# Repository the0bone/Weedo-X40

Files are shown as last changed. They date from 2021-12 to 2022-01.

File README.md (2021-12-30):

# Weedo-X40
My work for the Weedo X40 IDEX 3D printer

## Youtube Review (german)
Watch and Like my Video on YouTube. Even if you don't understand German, YouTube will give me some Cents for your click.
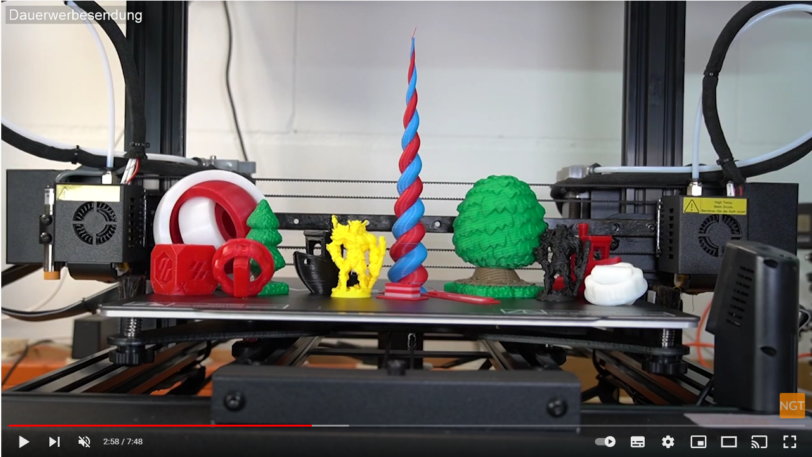
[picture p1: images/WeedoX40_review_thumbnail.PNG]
German Weedo X40(v2) 3D Drucker Review (https://www.youtube.com/watch?v=y7d468NICiw "German Weedo X40(v2) 3D Drucker Review")


# PrusaSlicer Profile
While PrusaSlicer 2.4 includes PaintOn MultiMaterial, it is the optimal Slicer for the Weedo X40.
Therefor I tried to create Profiles that will run with the default firmware.
The released profiles are for:

- Single Nozzle Print  
Use the left Extruder to make a single print. The options to select Mirror or Duplication via the screen on the printer are not available.

- Dual Nozzle Print  
Use both  Extruder to make a single print. Use a wipe tower to prime each nozzle before it will print.
Use Purging Volumes on the right and set it to 30mm² in the advanced section, if that is not included in the profile.

- Double Nozzle Print  
Because the selection is not available from the print screen, you can directly slice the object for that mode. You can also only see half of the print bed.

# RepRap conversion
Follow me along how I turned the X40 into a Printer using RepRap Firmware. [--> Go to RRF](RRF/)

# Donations
If you like, you can let Amazon pay some donations to me by using this affiliate link for your next pruchases on Amazon Germany: https://amzn.to/3cwmAMx

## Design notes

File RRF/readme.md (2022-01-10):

# Weedo X40 transition into RepRap Firmware printer

You need:
* Weedo X40(v2)
* Fysetc Big Dipper
* (alternative: Duet 3 Mini 5+ & Duet 3 Expansion for at least 2 additional drivers=
* Wires
* [JST SM](https://amzn.to/3GhMfW4) & [JST XH](https://amzn.to/3omI1pY)
* Good Crimping Tool [ENGINEER PA-09](https://amzn.to/3os2x8O)
* Printed Holder (best in ABS (plus) and 5 outer perimeters)

## Wire Diagram
This is how I wired the IDEX printer with his two extruders, dual axis and all endstops.
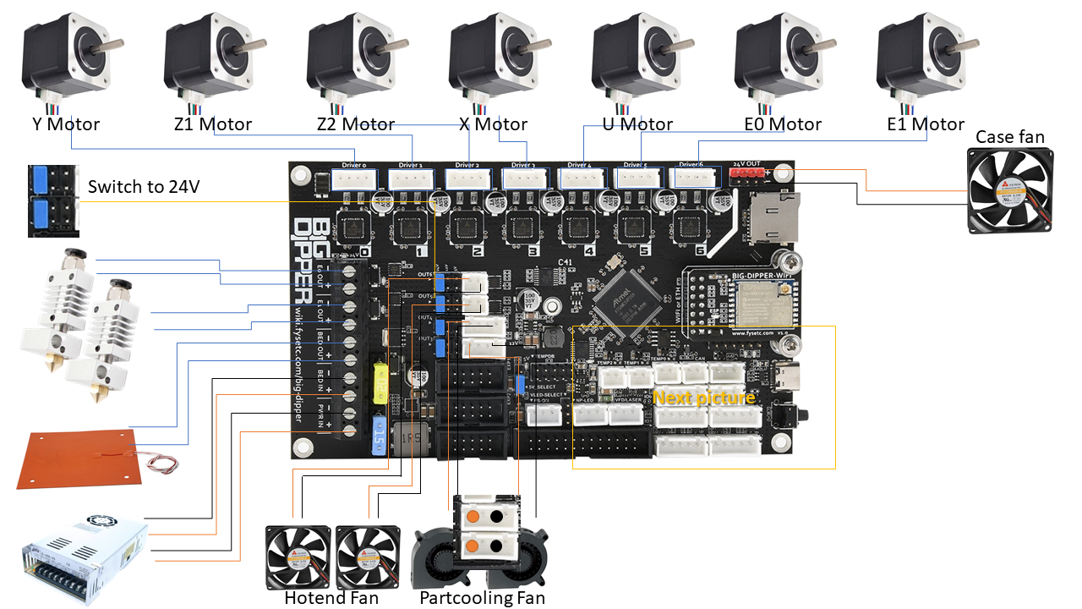
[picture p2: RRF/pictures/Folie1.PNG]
Pinning 1

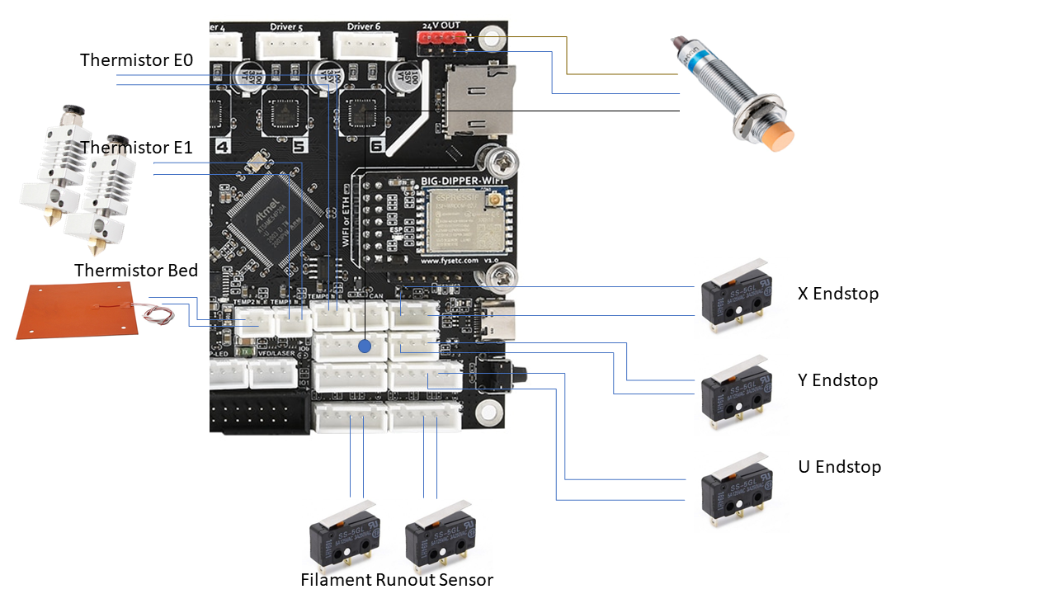
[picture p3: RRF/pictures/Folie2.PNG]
Pinning 2


If it is not clear to see, I also did some pictures.
For the Y and both Z Motors, I used the exising cables. For both E and X I bought new cables with 1m length.

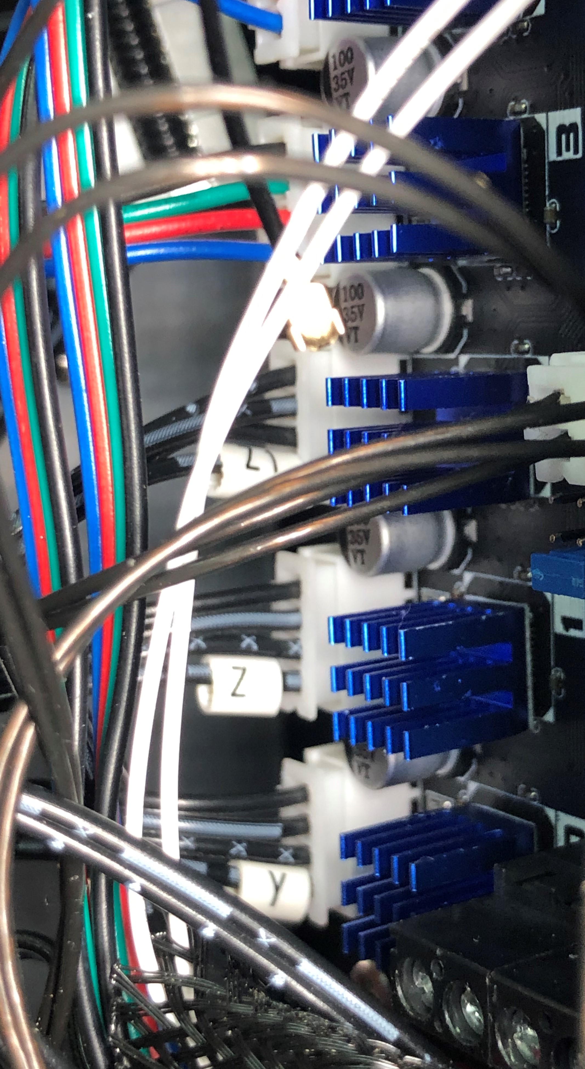
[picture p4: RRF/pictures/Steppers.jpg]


For the Fans on the Hotend you need to set the Jumpers to 24V. See the pinning on the picture.

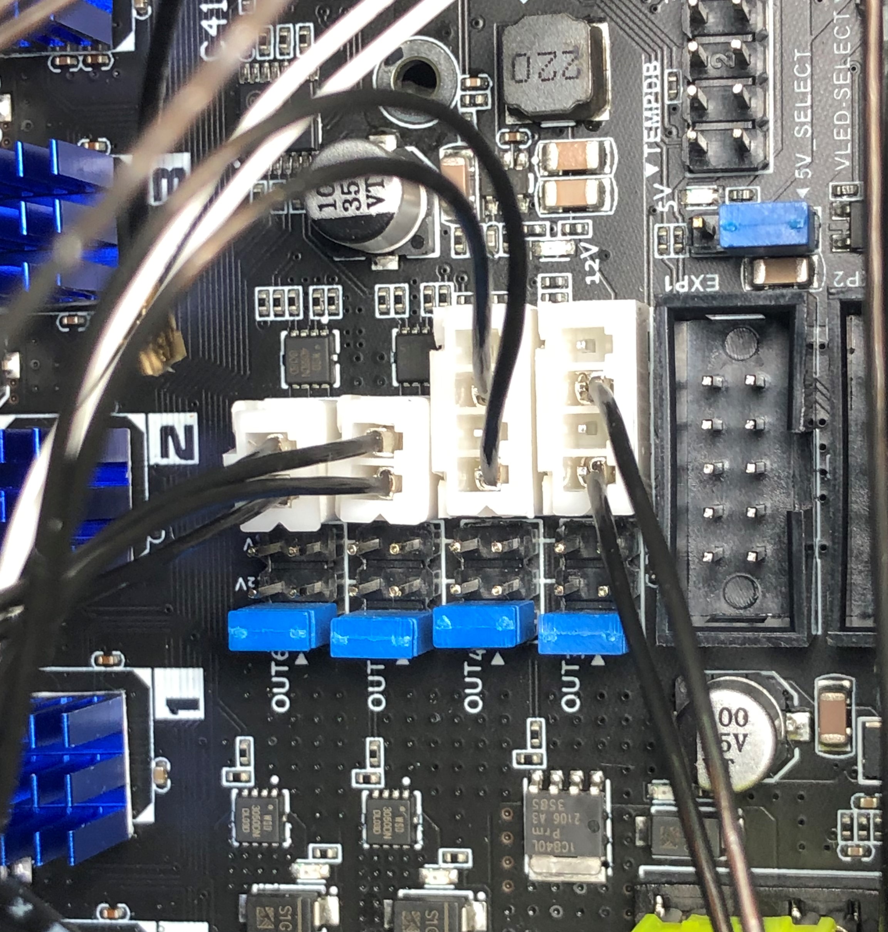
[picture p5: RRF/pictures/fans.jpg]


Also for the Endstops and the proximity sensor the Pinning is very impotant. There is no polarity but you have to take the right PINs in the JST-XH connectors.

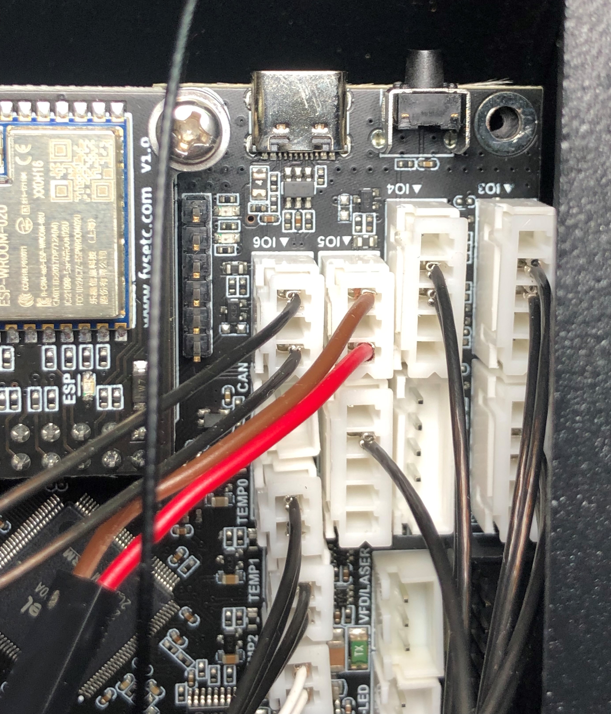
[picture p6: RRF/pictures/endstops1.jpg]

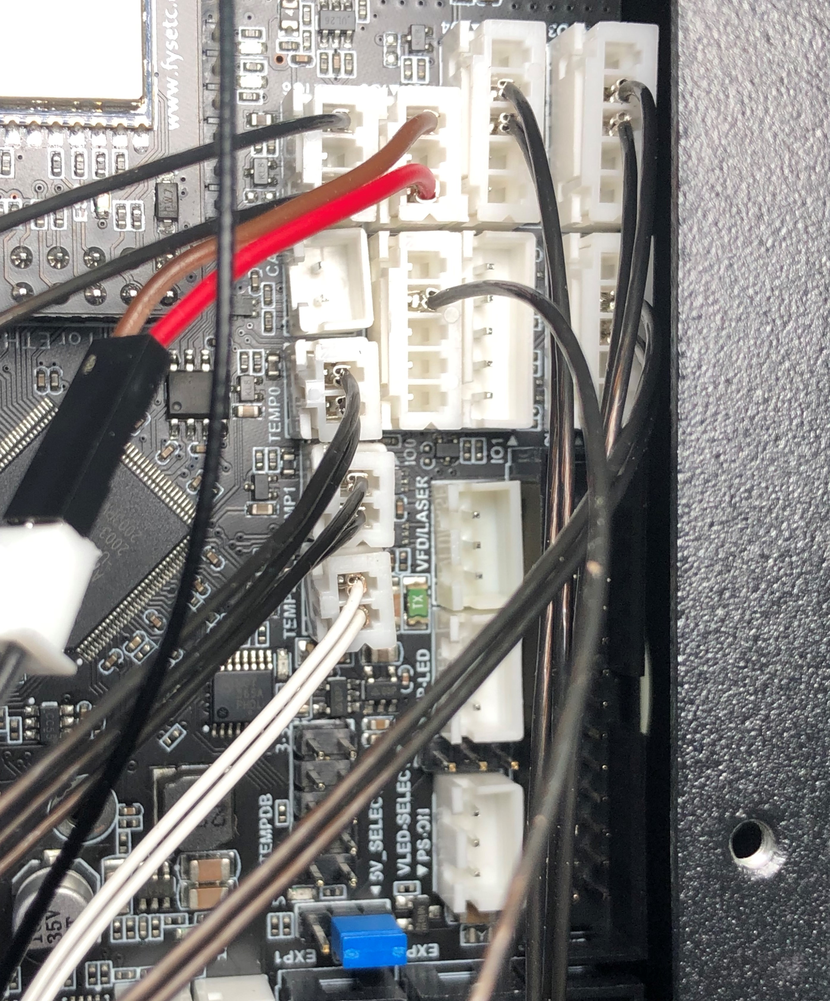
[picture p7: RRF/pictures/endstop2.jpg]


## PINout
| Function | PIN | comment |
| --- | --- | --- |
| Y Axis Motor | Driver 0 | |
| Z1 Axis Motor | Driver 1 | |
| Z2 Axis Motor | Driver 2 | |
| X Axis Motor | Driver 3 | left Printhead |
| U Axis Motor | Driver 4 | right Printhead |
| E0 Axis Motor | Driver 5 | left Extruder |
| E1 Axis Motor | Driver 6 | right Extruder |
| PSU 24V | Pwr in | |
| PSU 24V | Bed in | |
| Heated Bed | Bed out | |
| Hotend E0 | E0 out | left Printhead |
| Hotend E1 | E1 Out | right  Printhead |
| X-Endstop | io6.in | see pic for PIN |
| U-Endstop | io4.in | see pic for PIN |
| Y-Endstop | io5.in | see pic for PIN |
| Z-Probe | io0.in | only for Signal, see pic for PIN |
| Bed Thermistor | out0 |  |
| E0  Thermistor | out1 |  |
| E1  Thermistor | out2 |  |
| Case fan | 24V out |  |
| Z-Probe | 24V out |  |

## Results
Even if I'm still have the way down, the results are similar from quality but printed way faster with 80mm/sec that are also reached with the current settings.

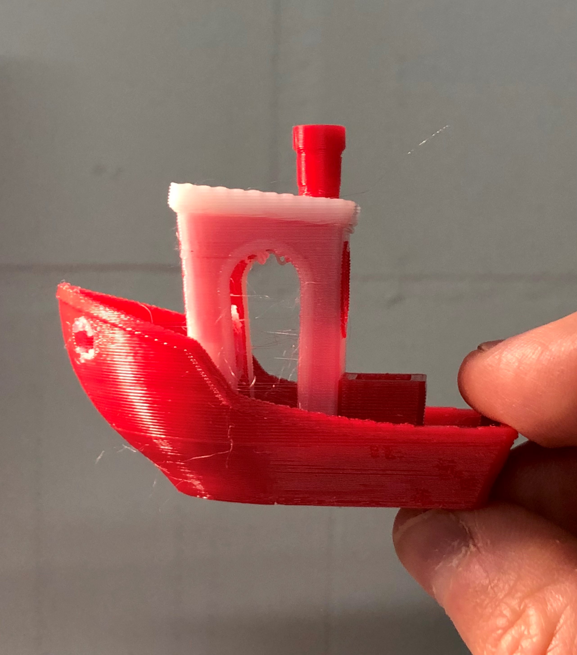
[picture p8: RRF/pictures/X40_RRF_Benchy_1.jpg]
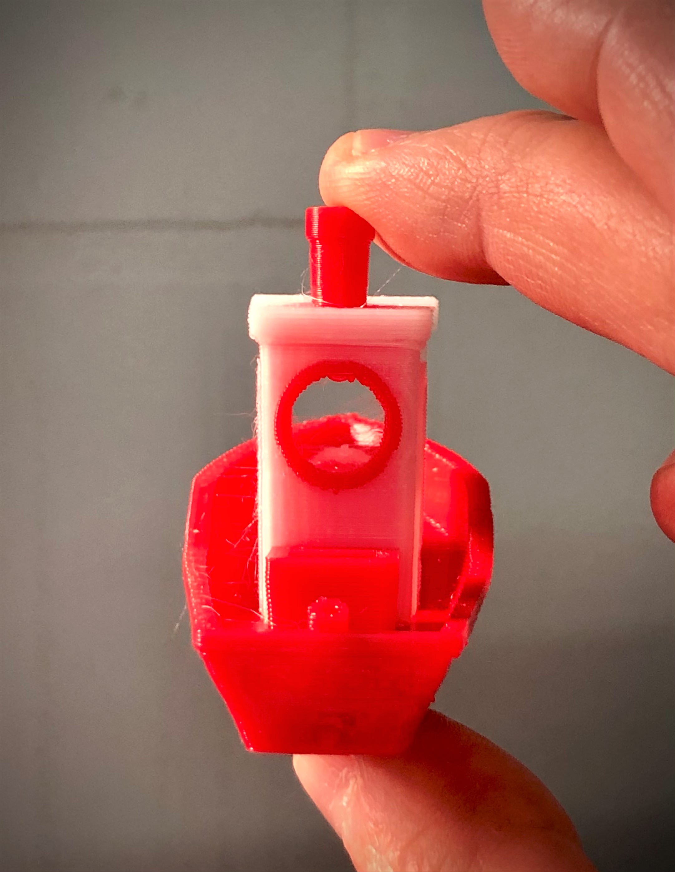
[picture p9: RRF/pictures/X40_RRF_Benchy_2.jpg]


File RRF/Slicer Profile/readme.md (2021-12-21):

Slicer Profiles for Prusa Slicer 2.4 that work together with the RRF on the Board.

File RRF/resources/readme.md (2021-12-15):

Each printer is a little different. You can carry over most of the setting. But some you need to tune for your printer.
Here is a link list of resources that you should visit to avoid the printer crashing into the bed for example.

First you need to tell the board about your WiFi.
I did that with Pronterface and this steps: https://duet3d.dozuki.com/Guide/1.)+Getting+Connected+to+your+Duet/7

Tipp: If you add ' before a letter, also Pronterface allowes small Letters. P'A'S'S'W'O'R'D = Password

Test and calibrate a Z probe https://duet3d.dozuki.com/Wiki/Test_and_calibrate_the_Z_probe#Section_Calibrate_the_Z_probe_trigger_height
Calibrate IDEX https://duet3d.dozuki.com/Wiki/ConfiguringMultipleIndependentXcarriagesCartesian#Section_Calibration

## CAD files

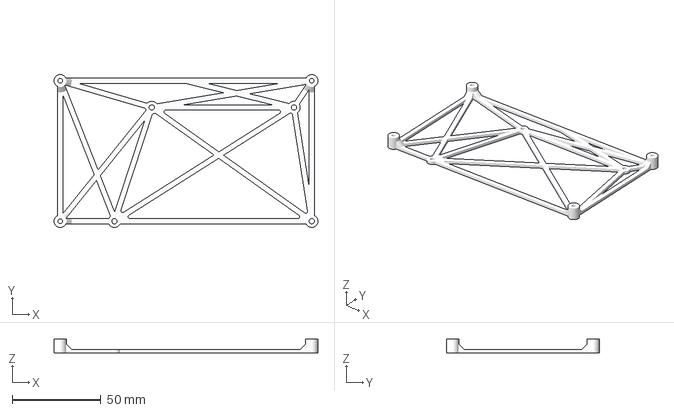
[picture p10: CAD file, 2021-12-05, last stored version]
Big Dipper/WeedoX40_FysetcBigDipper_Holder.3mf
148.5 x 86.0 x 8.00 mm

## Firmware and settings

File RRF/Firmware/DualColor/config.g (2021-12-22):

; Configuration file for Duet 3 Mini 5+ (firmware version 3.3)
; executed by the firmware on start-up
;
; generated by RepRapFirmware Configuration Tool v3.3.10 on Fri Dec 10 2021 21:27:52 GMT+0100 (Mitteleuropäische Normalzeit)

; General preferences
G90                                             ; send absolute coordinates...
M83                                             ; ...but relative extruder moves
M550 P"Weedo X40v2"                             ; set printer name

; Wait a moment for the CAN expansion boards to start
G4 S2

; Network
M551 P"reprap"                                  ; set password
M552 S1                                         ; enable network
M586 P0 S1                                      ; enable HTTP
M586 P1 S0                                      ; disable FTP
M586 P2 S0                                      ; disable Telnet

; Drives
M569 P0.0 S0 V50                                    ; Y Axis physical drive 0.0 goes backwards V50 to leave spreadCycle Mode
M569 P0.1 S0 V50                                    ; Z left Axis physical drive 0.1 goes backwards 
M569 P0.2 S0 V50                                    ; Z right Axis physical drive 0.2 goes backwards 
M569 P0.3 S1 V50                                    ; X left Axis physical drive 0.3 goes forwards 
M569 P0.4 S0 V50                                    ; X right Axis physical drive 0.4 goes backwards 
M569 P0.5 S1 V50                                    ; E left Axis physical drive 0.5 goes forwards 
M569 P0.6 S1 V50                                    ; E right Axis physical drive 0.6 goes forwards 
M584 X0.3 Y0.0 Z0.1:0.2 U0.4 E0.5:0.6               ; set drive mapping, Driver number for additional axes U for second X
M350 X16 Y16 Z16:16 U16 E16:16 I1                   ; configure microstepping with interpolation
M92 X94.14 Y94.14 Z400.00:400.00 U94.14 E94.90:94.90 ; set steps per mm
M566 X660.00 Y660.00 Z600.00:600.00 U660.00 E300.00:300.00   ; set maximum instantaneous speed changes (mm/min) (jerk) !!! mm/min = 60 x mm/sec
M203 X12000.00 Y7800.00 Z300.00:300.00 U12000.00 E1500.00:1500.00  ; set maximum speeds (mm/min) !!! mm/min = 60 x mm/sec
M201 X3000.00 Y3000.00 Z3000.00:3000.00 U3000.00 E3000.00:3000.00      ; set accelerations (mm/s^2)   (old 1000 and 20 for Z)
M906 X700 Y700 Z700:700 U700 E500:500 I30           ; set motor currents (mA) and motor idle factor in per cent
M84 S30                                             ; Set idle timeout

; Axis Limits
M208 X-51.80 U0 Y-11 Z0:0 S1                        ; set axis minima, X-51.8 for the Extruder to go negative into park position, S1 = set axis minimum
M208 X300.00 U351.80 Y305 Z400:400 S0               ; set axis maxima, U351.8 for the Extruder to go out of bed into park position, S0 = set axis maximum

; Endstops
M574 X1 S1 P"!io6.in"                            ; configure switch-type (e.g. microswitch) endstop for low end on X via pin io6.in
M574 U2 S1 P"!io4.in"                            ; configure switch-type (e.g. microswitch) endstop for high end on U via pin io4.in
M574 Y1 S1 P"!io5.in"                            ; configure switch-type (e.g. microswitch) endstop for low end on Y via pin io5.in
M574 Z1 S2                                      ; configure Z-probe endstop for low end on Z

; Z-Probe
M558 P5 C"!io0.in" H5 F240 T10000               ; set Z probe type to unmodulated and the dive height + speeds for Probing and Travel
G31 P500 X-35 Y0 Z1.030                           ; set Z probe trigger value, offset and trigger height
M557 X10:290 Y10:290 S50                        ; set Mesh bed size

; Heaters
M308 S0 P"temp2" Y"thermistor" T100000 B4092    ; configure sensor 0 as thermistor on pin temp2
M950 H0 C"out0" T0                              ; create bed heater output on out0 and map it to sensor 0
M307 H0 B0 R0.317 C372.9 D3.16 S1.00 V24.1      ; disable bang-bang mode for the bed heater and set PWM limit with PID tune
M140 H0                                         ; map heated bed to heater 0
M143 H0 S100                                    ; set temperature limit for heater 0 to 100C
M308 S1 P"temp0" Y"thermistor" T100000 B4092    ; configure sensor 1 as thermistor on pin temp0
M950 H1 C"out1" T1                              ; create nozzle heater output on out1 and map it to sensor 1
M307 H1 B0 R3.302 C205.8 D7.27 S1.00 V24.1      ; disable bang-bang mode for the bed heater and set PWM limit with PID tune
M143 H1 S260                                    ; set temperature limit for heater 1 to 260C
M308 S2 P"temp1" Y"thermistor" T100000 B4092    ; configure sensor 2 as thermistor on pin temp1
M950 H2 C"out2" T2                              ; create nozzle heater output on out2 and map it to sensor 2
M307 H2 B0 R3.528 C210.1 D7.19 S1.00 V24.1      ; disable bang-bang mode for the bed heater and set PWM limit with PID tune
M143 H2 S260                                    ; set temperature limit for heater 2 to 260C

; Fans
M950 F0 C"out6" Q500                            ; create fan 0 on pin out6 and set its frequency
M106 P0 C"Fan0 E0" S1 H1 T45                    ; set fan 0 name and value. Thermostatic control is turned on
M950 F1 C"out5" Q500                            ; create fan 1 on pin out5 and set its frequency
M106 P1 C"Fan0 E1" S1 H2 T45                    ; set fan 1 name and value. Thermostatic control is turned on
M950 F2 C"out4" Q500                            ; create fan 2 on pin out4 and set its frequency
M106 P2 C"Part E0" S0 I0 H-1                    ; set fan 2 name and value. Thermostatic control is turned off
M950 F3 C"out3" Q500                            ; create fan 3 on pin out3 and set its frequency
M106 P3 C"Part E1" S0 I0 H-1                    ; set fan 3 name and value. Thermostatic control is turned off

; Tools
M563 P0 S"Nozzle left" D0 H1 F2                 ; define tool 0
G10 P0 X0 Y0 Z0                                 ; set tool 0 axis offsets
G10 P0 R0 S0                                    ; set initial tool 0 active and standby temperatures to 0C
M572 D0 S1.1                                    ; Preasure Advanced Seetings for Tool 0
M563 P1 S"Nozzle right" D1 H2 X3 F3             ; define tool 1, X3 tells the firmware that the X axis should be mapped to axis #3 which is the U axis.
G10 P1 Y0 U-3.4 Z0                            ; set tool 1 axis offsets
G10 P1 R0 S0                                    ; set initial tool 1 active and standby temperatures to 0C
M572 D1 S1.1                                    ; Preasure Advanced Seetings for Tool 1

; Custom settings are not defined

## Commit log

2021-11-21 Inital Release of 3 PrusaSlicer 2.4 Profiles
    All 3 worked for me.
    Like always with Prusa Slicer: Fully Restart the X40 before printing a g-code. Sometimes the Toolheads crash into each other for no reason. Even if you just loaded filament before the print.
    Also restart the printer after the print.
2021-12-05 Add files via upload
    Version 1 of Weedo X40 Holder for FYSETC Big Dipper Board
    [WeedoX40_FysetcBigDipper_Holder.3mf]
2021-12-21 Add files via upload
    Firmware: RepRapFirmware for Duet 3 Mini 5+ 3.4.0beta7 (2021-12-16) for Weedo X40 Dual Color Printing
    [bed.g, config.g, homeall.g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]
2021-12-21 Update Preasure Advanced
    [config.g]
2021-12-22 Update config.g
    Speeds
    [config.g]
2021-12-30 change in folder structure
    [bed.g, config.g, homeall.g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]
